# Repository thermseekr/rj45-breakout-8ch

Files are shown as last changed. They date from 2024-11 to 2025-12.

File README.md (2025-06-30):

# RJ45-BREAKOUT-8CH

Breakout board for 8x RJ45 connectors.

This board is mounted inside the automation cabinet to connect cables coming from up to eight 1-3 gang wall switch boxes, and routes those cables to an automation system.

The dimensions are such that the board can be mounted on a PCB DIN rail holder from the Brazilian manufacturer Metaltex, check [here](https://www.metaltex.com.br/produtos/componentes/suportes/sp7-suporte-para-montagem-de-placa-de-circuito-impresso-em-trilho-din) for details.

Also check [here](https://github.com/thermseekr/RJ45-breakout-1ch) for the board that mounts inside the wall switch boxes.

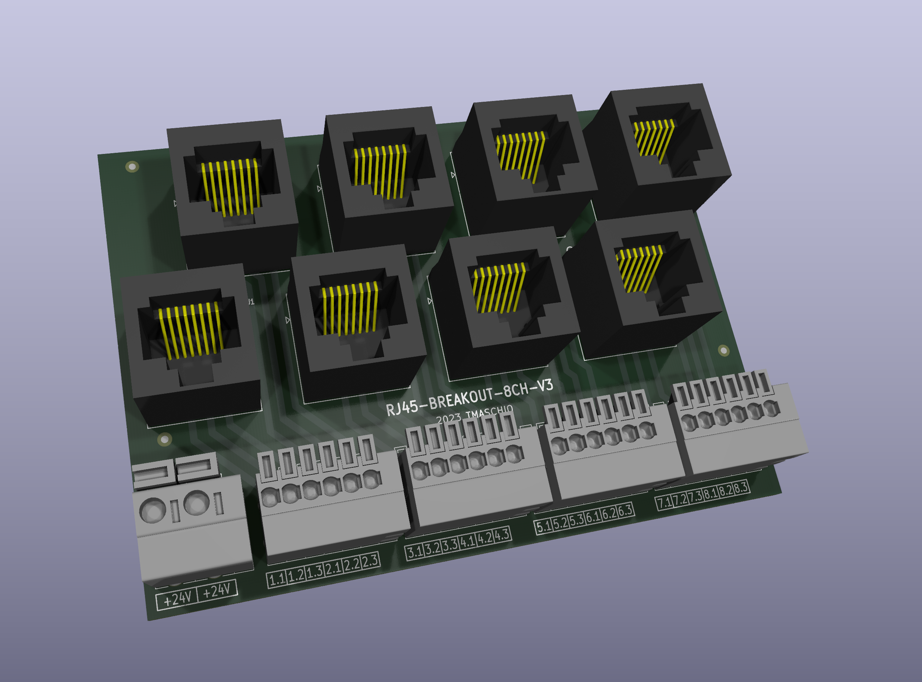
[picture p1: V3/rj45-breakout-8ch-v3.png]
RJ45-BREAKOUT-8CH-V3


## VERSION HISTORY

V3 - More space saving: RJ45 jacks changed from right angle to vertical, signal connectors changed from pitch 5.08mm screw to pitch 2.54mm spring cage. Power connector changed from screw to spring cage with two poles to be able to send power to the next board.

V2 - Single power connector instead one per channel, RJ45 jacks repositioned to save space.

V1 - Initial release.

## LICENSE

This project is licensed under the [Creative Commons BY-NC 4.0 License](https://creativecommons.org/licenses/by-nc/4.0/).
Commercial use is not permitted without prior written consent. See the [LICENSE.txt](LICENSE.txt) file for details.

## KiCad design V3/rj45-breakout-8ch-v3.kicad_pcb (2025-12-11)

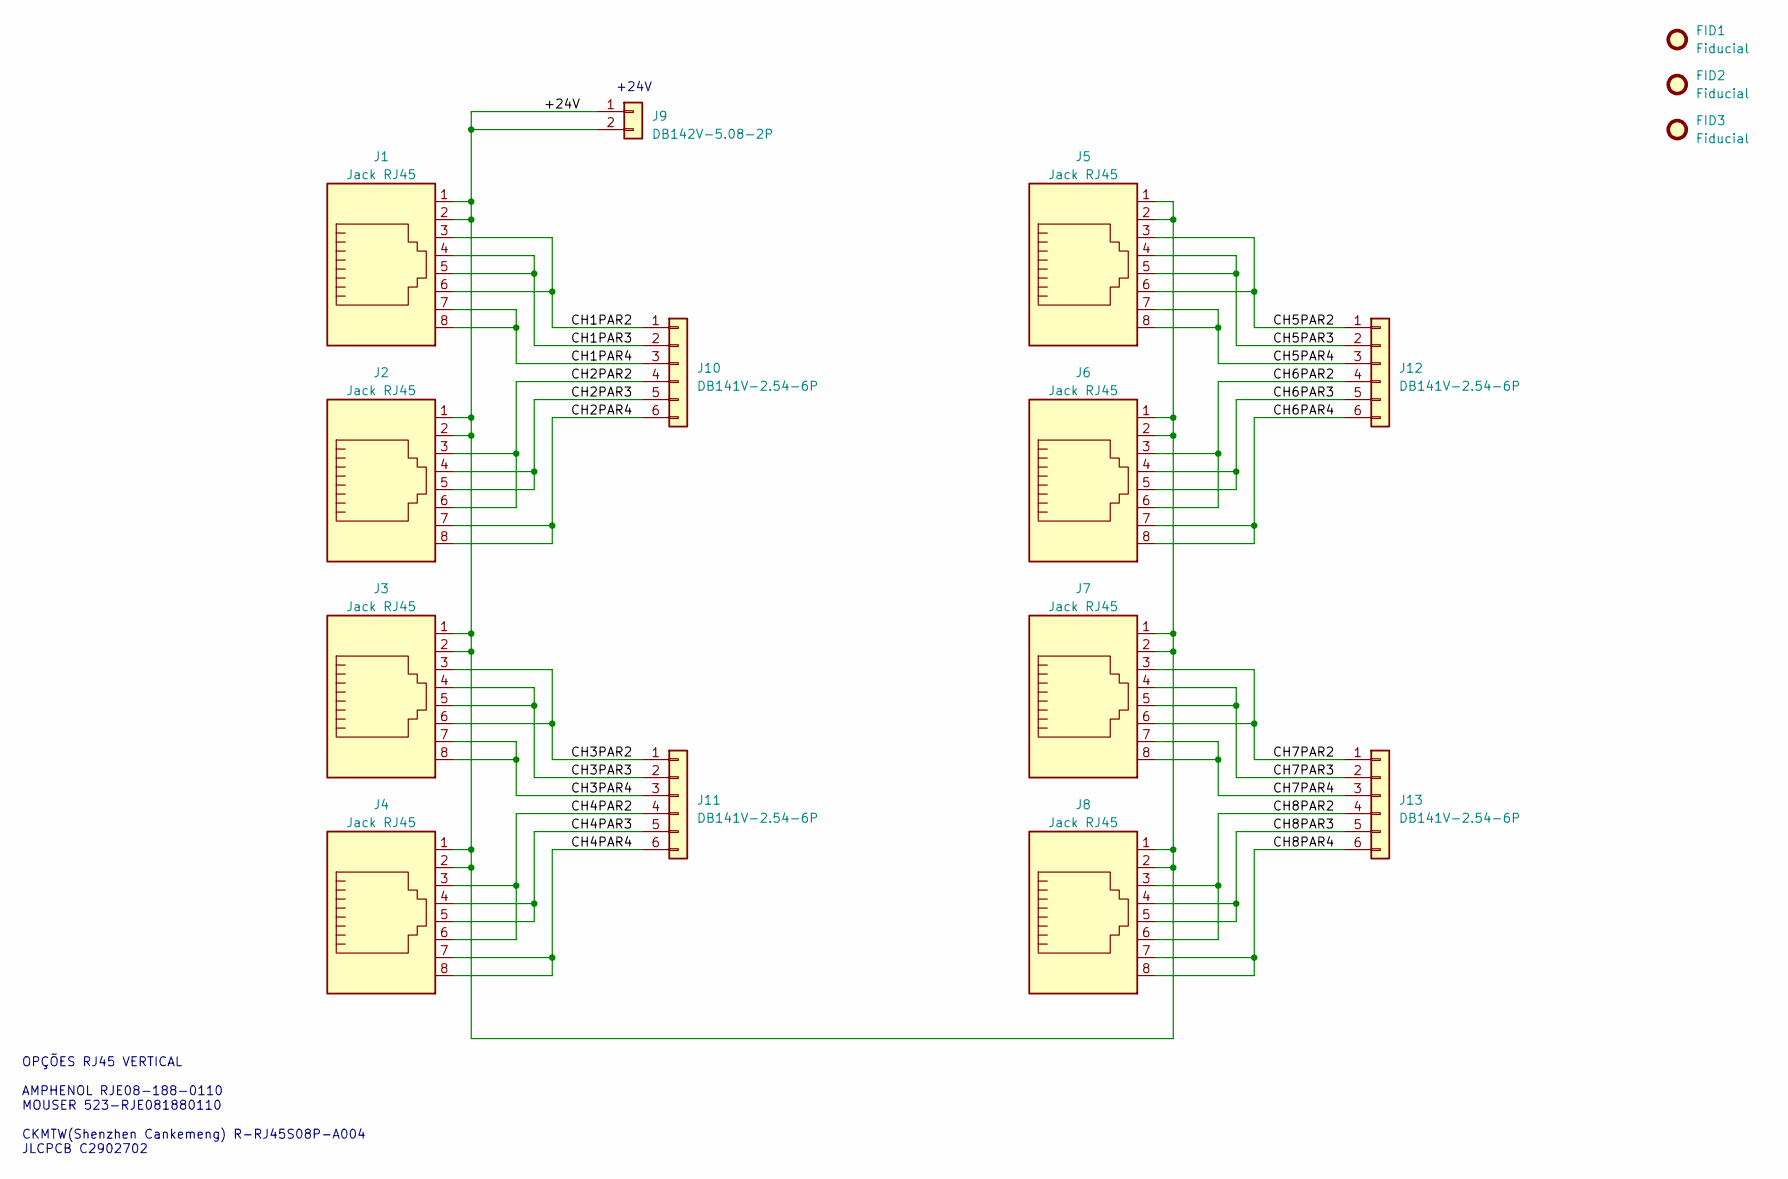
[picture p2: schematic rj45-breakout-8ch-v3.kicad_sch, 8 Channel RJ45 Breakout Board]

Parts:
FID1, FID2, FID3: Fiducial; Fiducial_1mm_Mask2mm
J1, J2, J3, J4, J5, J6, J7, J8: Jack RJ45; RJ45_CKMTW_R-RJ45S08P-A004; Mfr PN R-RJ45S08P-A004; JLCPCB BOM 1
J9: DB142V-5.08-2P; TerminalBlock_Dibo_DB142V-5.08-2P_1x02_P5.08mm_Vertical; Mfr PN DB142V-5.08-2P; JLCPCB BOM 1
J10, J11, J12, J13: DB141V-2.54-6P; TerminalBlock_Dibo_DB141V-2.54-6P_1x06_P2.54mm_Vertical; Mfr PN DB141V-2.54-6P; JLCPCB BOM 1

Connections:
/+24V: J1.1, J1.2, J2.1, J2.2, J3.1, J3.2, J4.1, J4.2, J5.1, J5.2, J6.1, J6.2, J7.1, J7.2, J8.1, J8.2, J9.1, J9.2
/CH1PAR2: J1.3, J1.6, J10.1
/CH1PAR3: J1.4, J1.5, J10.2
/CH1PAR4: J1.7, J1.8, J10.3
/CH2PAR2: J2.3, J2.6, J10.4
/CH2PAR3: J2.4, J2.5, J10.5
/CH2PAR4: J2.7, J2.8, J10.6
/CH3PAR2: J3.3, J3.6, J11.1
/CH3PAR3: J3.4, J3.5, J11.2
/CH3PAR4: J3.7, J3.8, J11.3
/CH4PAR2: J4.3, J4.6, J11.4
/CH4PAR3: J4.4, J4.5, J11.5
/CH4PAR4: J4.7, J4.8, J11.6
/CH5PAR2: J5.3, J5.6, J12.1
/CH5PAR3: J5.4, J5.5, J12.2
/CH5PAR4: J5.7, J5.8, J12.3
/CH6PAR2: J6.3, J6.6, J12.4
/CH6PAR3: J6.4, J6.5, J12.5
/CH6PAR4: J6.7, J6.8, J12.6
/CH7PAR2: J7.3, J7.6, J13.1
/CH7PAR3: J7.4, J7.5, J13.2
/CH7PAR4: J7.7, J7.8, J13.3
/CH8PAR2: J8.3, J8.6, J13.4
/CH8PAR3: J8.4, J8.5, J13.5
/CH8PAR4: J8.7, J8.8, J13.6

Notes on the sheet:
OPÇÕES RJ45 VERTICAL AMPHENOL RJE08-188-0110 MOUSER 523-RJE081880110 CKMTW(Shenzhen Cankemeng) R-RJ45S08P-A004 JLCPCB C2902702
+24V

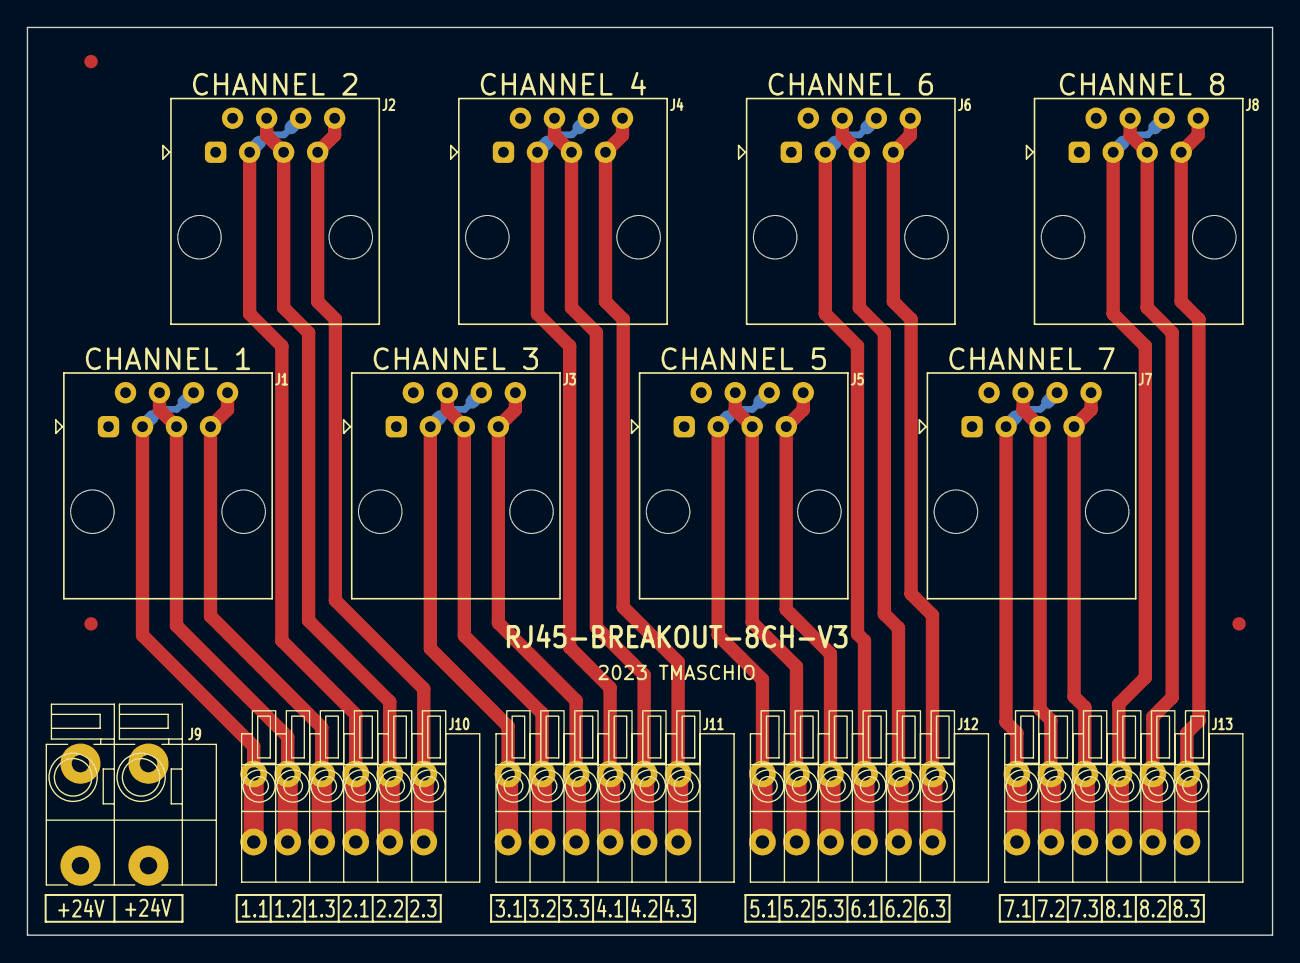
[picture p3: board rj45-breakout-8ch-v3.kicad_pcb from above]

Board: 2 copper layers, 93.0 x 67.8 mm, 16 parts (0 on the bottom side), 25 nets.

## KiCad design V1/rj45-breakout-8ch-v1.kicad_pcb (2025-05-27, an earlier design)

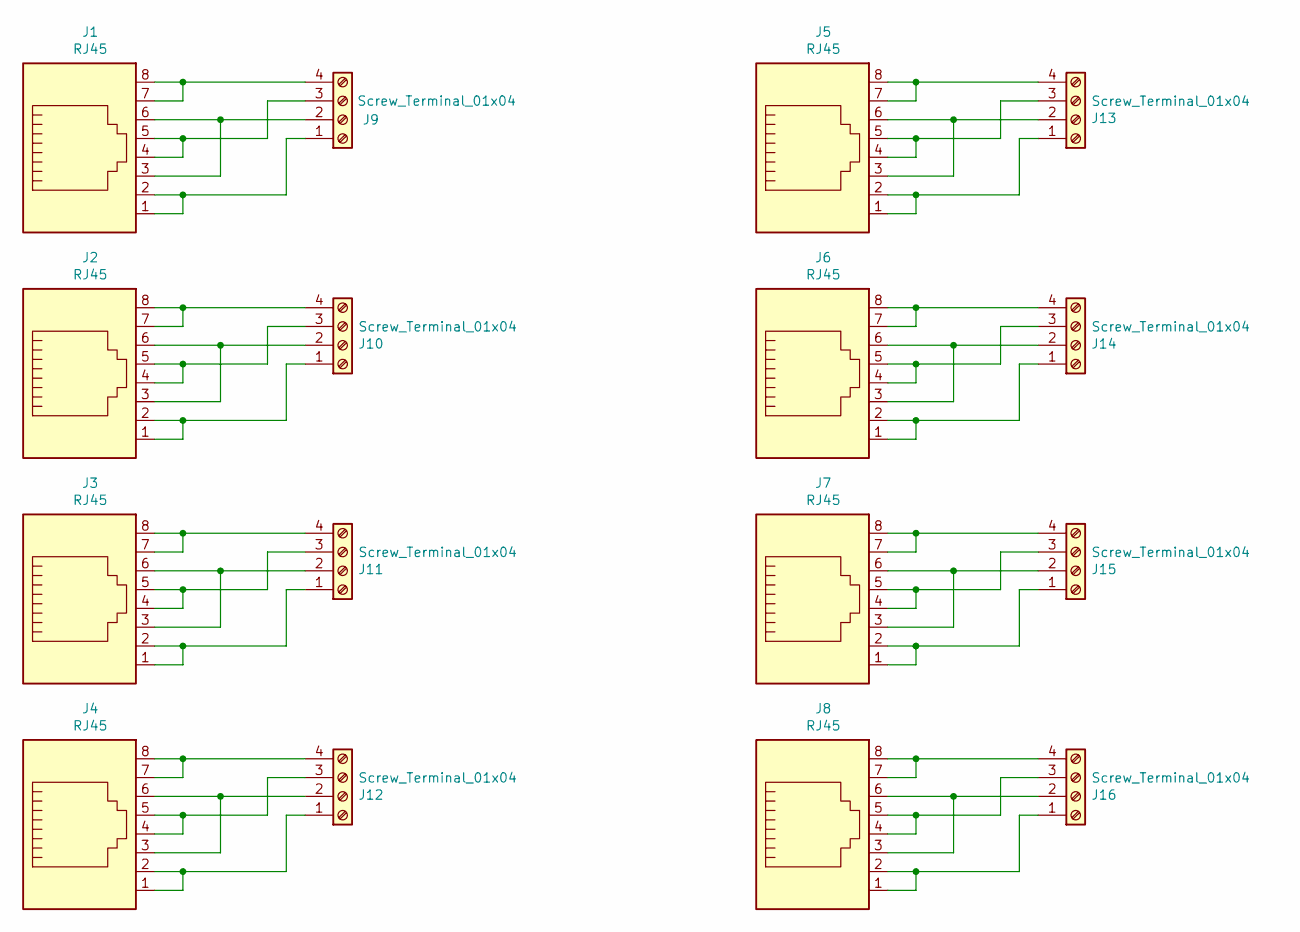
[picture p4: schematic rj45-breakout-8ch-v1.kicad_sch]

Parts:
J1, J2, J3, J4, J5, J6, J7, J8: RJ45; RJ45_Amphenol_RJHSE5080; Mfr PN RJHSE-5080
J9, J10, J11, J12, J13, J14, J15, J16: Screw_Terminal_01x04; TerminalBlock_Phoenix_MKDS-3-4-5.08_1x04_P5.08mm_Horizontal; Mfr PN 2x BR902V

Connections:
unnamed: J1.1, J1.2, J9.1
unnamed: J1.3, J1.6, J9.2
unnamed: J1.4, J1.5, J9.3
unnamed: J1.7, J1.8, J9.4
unnamed: J2.1, J2.2, J10.1
unnamed: J2.3, J2.6, J10.2
unnamed: J2.4, J2.5, J10.3
unnamed: J2.7, J2.8, J10.4
unnamed: J3.1, J3.2, J11.1
unnamed: J3.3, J3.6, J11.2
unnamed: J3.4, J3.5, J11.3
unnamed: J3.7, J3.8, J11.4
unnamed: J4.1, J4.2, J12.1
unnamed: J4.3, J4.6, J12.2
unnamed: J4.4, J4.5, J12.3
unnamed: J4.7, J4.8, J12.4
unnamed: J5.1, J5.2, J13.1
unnamed: J5.3, J5.6, J13.2
unnamed: J5.4, J5.5, J13.3
unnamed: J5.7, J5.8, J13.4
unnamed: J6.1, J6.2, J14.1
unnamed: J6.3, J6.6, J14.2
unnamed: J6.4, J6.5, J14.3
unnamed: J6.7, J6.8, J14.4
unnamed: J7.1, J7.2, J15.1
unnamed: J7.3, J7.6, J15.2
unnamed: J7.4, J7.5, J15.3
unnamed: J7.7, J7.8, J15.4
unnamed: J8.1, J8.2, J16.1
unnamed: J8.3, J8.6, J16.2
unnamed: J8.4, J8.5, J16.3
unnamed: J8.7, J8.8, J16.4

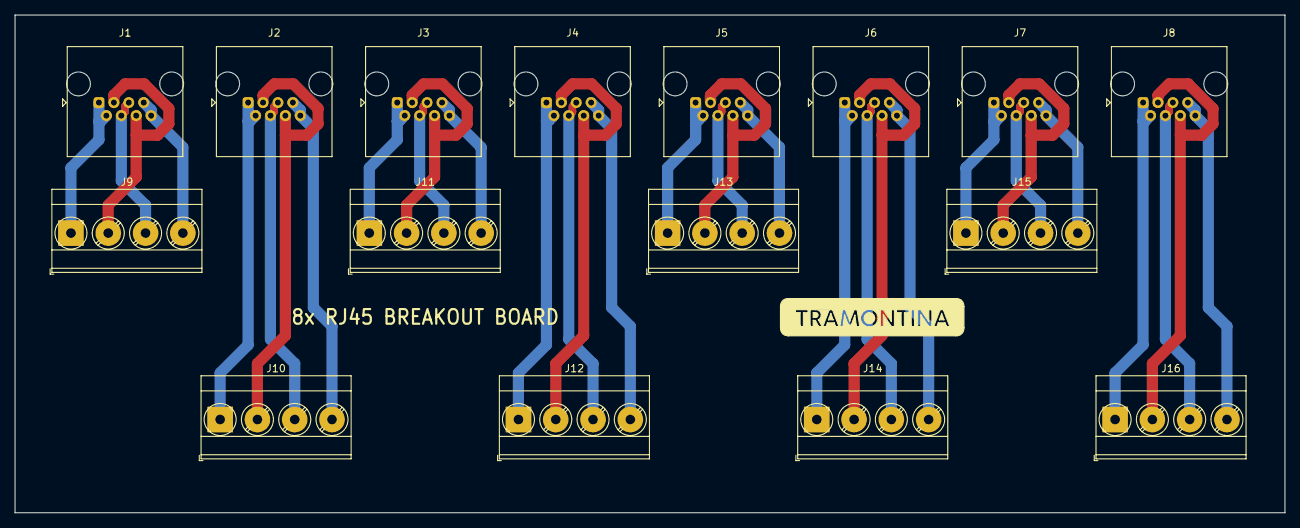
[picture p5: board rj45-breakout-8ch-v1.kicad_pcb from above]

Board: 2 copper layers, 173.0 x 67.8 mm, 16 parts (0 on the bottom side), 32 nets.

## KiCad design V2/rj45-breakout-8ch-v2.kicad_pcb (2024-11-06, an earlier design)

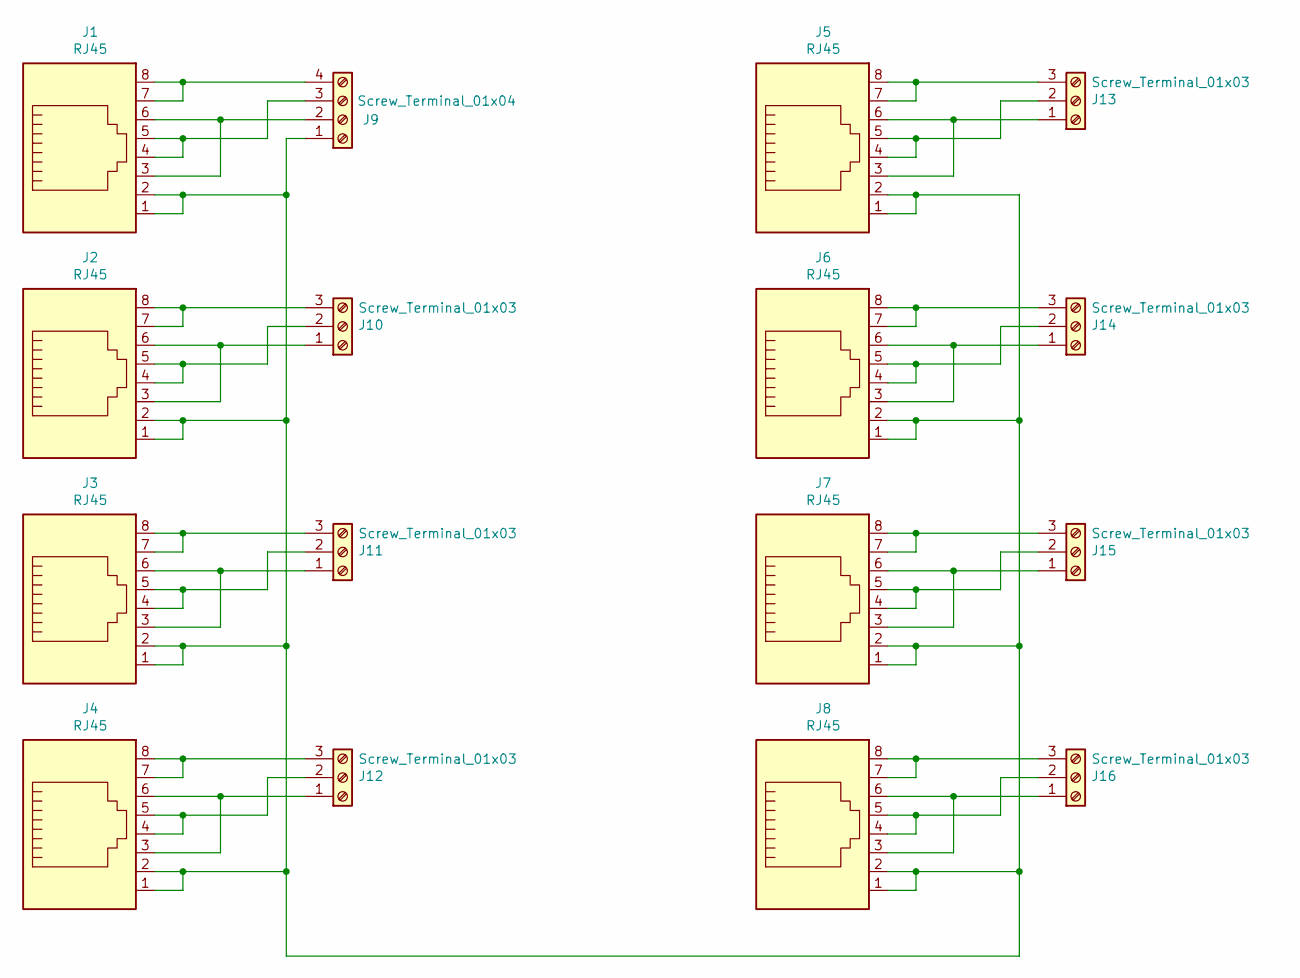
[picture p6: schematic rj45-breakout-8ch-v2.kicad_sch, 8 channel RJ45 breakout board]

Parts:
J1, J2, J3, J4, J5, J6, J7, J8: RJ45; RJ45_Amphenol_RJHSE5080; Mfr PN RJHSE-5080
J9: Screw_Terminal_01x04; TerminalBlock_Phoenix_MKDS-3-4-5.08_1x04_P5.08mm_Horizontal; Mfr PN 2x BR902V
J10, J11, J12, J13, J14, J15, J16: Screw_Terminal_01x03; TerminalBlock_Phoenix_MKDS-3-3-5.08_1x03_P5.08mm_Horizontal; Mfr PN BR903V

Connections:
unnamed: J1.1, J1.2, J2.1, J2.2, J3.1, J3.2, J4.1, J4.2, J5.1, J5.2, J6.1, J6.2, J7.1, J7.2, J8.1, J8.2, J9.1
unnamed: J1.3, J1.6, J9.2
unnamed: J1.4, J1.5, J9.3
unnamed: J1.7, J1.8, J9.4
unnamed: J2.3, J2.6, J10.1
unnamed: J2.4, J2.5, J10.2
unnamed: J2.7, J2.8, J10.3
unnamed: J3.3, J3.6, J11.1
unnamed: J3.4, J3.5, J11.2
unnamed: J3.7, J3.8, J11.3
unnamed: J4.3, J4.6, J12.1
unnamed: J4.4, J4.5, J12.2
unnamed: J4.7, J4.8, J12.3
unnamed: J5.3, J5.6, J13.1
unnamed: J5.4, J5.5, J13.2
unnamed: J5.7, J5.8, J13.3
unnamed: J6.3, J6.6, J14.1
unnamed: J6.4, J6.5, J14.2
unnamed: J6.7, J6.8, J14.3
unnamed: J7.3, J7.6, J15.1
unnamed: J7.4, J7.5, J15.2
unnamed: J7.7, J7.8, J15.3
unnamed: J8.3, J8.6, J16.1
unnamed: J8.4, J8.5, J16.2
unnamed: J8.7, J8.8, J16.3

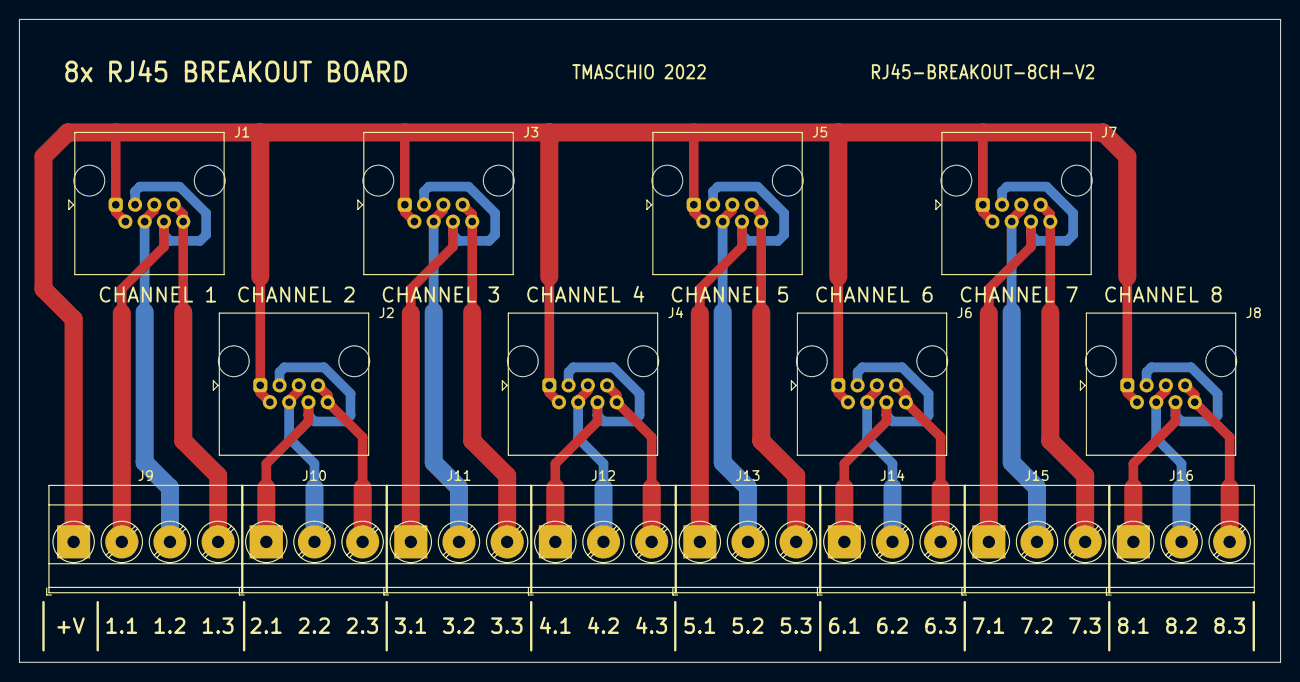
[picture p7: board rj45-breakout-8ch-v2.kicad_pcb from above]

Board: 2 copper layers, 133.0 x 67.8 mm, 16 parts (0 on the bottom side), 25 nets.

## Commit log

2022-02-02 Initial upload
    [RJ45-breakout_8ch-V1-B_Cu.gbr, RJ45-breakout_8ch-V1-B_Mask.gbr, RJ45-breakout_8ch-V1-Edge_Cuts.gbr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]
2022-02-05 updates to components
    [RJ45-breakout_8ch-V1.kicad_pcb, RJ45-breakout_8ch-V1.kicad_sch, RJ45-breakout_8ch-V2.kicad_pcb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]
2022-02-28 Cleanup after migration to Kicad 6
    [RJ45-breakout_8ch-V2.sch]
2022-04-01 PCB tweaks
    [RJ45-breakout_8ch-V2.kicad_pcb, RJ45-breakout_8ch-V2.kicad_sch]
2022-04-03 rename files to new schema
    [RJ45-breakout-8ch-V1.kicad_pcb, RJ45-breakout-8ch-V1.kicad_sch, RJ45-breakout-8ch-V2.kicad_pcb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]
2023-05-21 Update board image
2023-06-22 Update V1 Kicad version
2023-08-06 Part numbers update
    [rj45-breakout-8ch-v3.kicad_pcb, rj45-breakout-8ch-v3.kicad_sch]
2023-08-11 Added information on RJ45 connectors
    [rj45-breakout-8ch-v3.kicad_sch]
2023-08-19 Connectors rotated 180deg
    [rj45-breakout-8ch-v3.kicad_pcb, rj45-breakout-8ch-v3.kicad_sch]
2023-08-21 Added text regarding RJ45 connectors
    [rj45-breakout-8ch-v3.kicad_sch]
2023-08-22 Layout tweakings
    [rj45-breakout-8ch-v3.kicad_pcb, rj45-breakout-8ch-v3.kicad_sch]
2023-08-23 Footprints updated
    [rj45-breakout-8ch-v3.kicad_pcb, rj45-breakout-8ch-v3.kicad_sch]
2023-08-23 Grid changed to mm
    [rj45-breakout-8ch-v3.kicad_pcb]
2023-08-24 Align parts and tracks to mm grid
    [rj45-breakout-8ch-v3.kicad_pcb]
2023-08-24 Move to mm grid
    [rj45-breakout-8ch-v3.kicad_pcb]
2023-08-26 Cosmetic enhancements to PCB
    [rj45-breakout-8ch-v3.kicad_pcb, rj45-breakout-8ch-v3.kicad_sch]
2023-09-05 New image
    [rj45-breakout-8ch-v3.kicad_pcb]
2023-09-06 Renaming to lowercase
    [small-rj45-breakout-8ch-v1.kicad_pcb, small-rj45-breakout-8ch-v1.kicad_sch, small-rj45-breakout-8ch-v2.kicad_pcb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]
2024-10-02 Update to Kicad 8
    [rj45-breakout-8ch-v2.kicad_pcb, rj45-breakout-8ch-v2.kicad_sch, rj45-breakout-8ch-v3.kicad_pcb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]
2024-11-06 Update to Kicad V8
    [rj45-breakout-8ch-v3.kicad_pcb]
2024-11-23 Update components
    [rj45-breakout-8ch-v3.kicad_pcb, rj45-breakout-8ch-v3.kicad_sch]
2025-04-14 Prefab checks
    [rj45-breakout-8ch-v3.kicad_pcb]
2025-11-27 Kicad version update
    [rj45-breakout-8ch-v3.kicad_pcb, rj45-breakout-8ch-v3.kicad_sch]
2025-12-09 Revision for manufacturing
    [rj45-breakout-8ch-v3.kicad_pcb, rj45-breakout-8ch-v3.kicad_sch]
2025-12-10 Small updates before fabrication
    [rj45-breakout-8ch-v3.kicad_pcb]
2025-12-10 Revising before production
    [rj45-breakout-8ch-v3.kicad_pcb, rj45-breakout-8ch-v3.kicad_sch]
2025-12-11 Revising for fabrication
    [rj45-breakout-8ch-v3.kicad_pcb, rj45-breakout-8ch-v3.kicad_sch]
